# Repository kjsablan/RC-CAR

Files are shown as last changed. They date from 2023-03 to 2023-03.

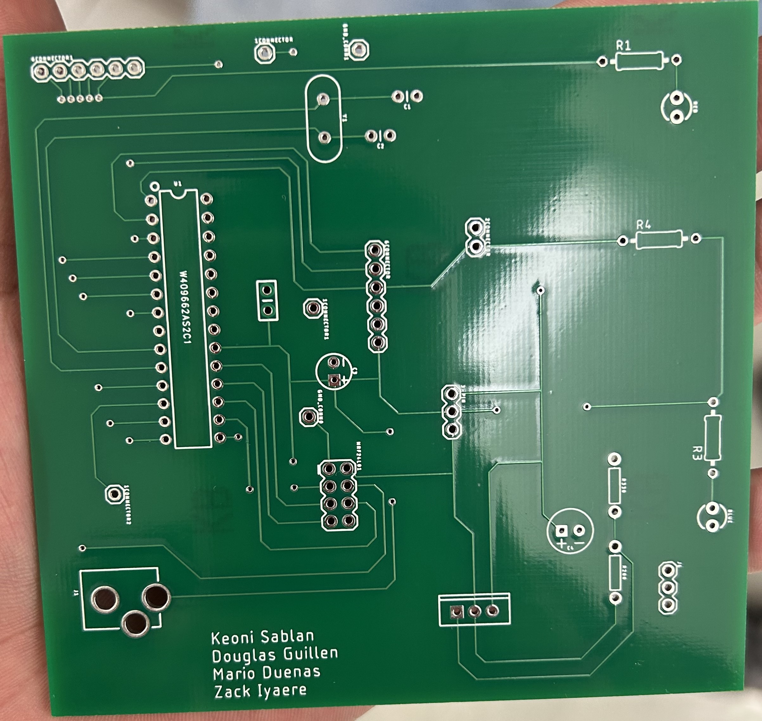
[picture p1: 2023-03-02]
PCB.jpg

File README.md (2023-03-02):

# RC CAR
 PCB Design for an RC CAR (Senior Project)
This is a senior design project this is currently in development and will be complete by May 2023.
The Purpose is to design a Printed Circuit Board using the Eagle software to create a circuit schematic, convert it to a board layout, generate the gerber files, and send the files out to a company to print the board. 
Then Using a microcontroller (ATMega 328P) develop firmware and create a product (RC Car)
My group has completed creating the board and now are building the RC Car.
All files (Project Report/Journal article) are still not completed and will be complete at the end of this semester (May 2023)

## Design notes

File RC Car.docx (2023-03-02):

RC Car

Description:

In this project our group is going to build an RC Car from scratch using a ATmega328P microcontroller and a printed circuit board. The goal of this project is to be able to build a functioning radio controlled operated car using a PCB with minimal parts.

The RC car will be powered by a 9V power supply which will be connected to a L298N H-bridge motor driver, four 3V DC motors, an ATmega 328, and an NRF24L01 radio module. The H-bridge can take a 5V-35V voltage and has an on-board 5V voltage regulator, if the voltage from the power supply is less than 12V then we can use the onboard 5V input as an output to power the ATmega 328 which is what we will be doing. The H-bridge has a voltage drop of .7V at each input (2) for the connection of the motors, taking this into account we will have to supply an additional 1.4V to the H-Bridge to power the DC motors.

The H-Bridge will output 5V to power the ATmega 328, from here the NRF24L01 will be connected to the 3.3V Vout pin of the ATmega 328 to power the device. The NRF24L01 also has an onboard 5V voltage regulator. Our group will also build a remote controller to control the RC car, this will consist of a 7.4V-9V power supply, Arduino Uno/Nano, and a joystick. Firmware will be added onto both and is shown below.

Areas of Responsibility:

Keoni Sablan: RC Car Electrical circuit/components

Douglas Guillen: Remote control electrical circuit/PCB design

Mario Duenas: Firmware/ PCB design

Zack Iyaere: Firmware Remote control

BOM

parts(data sheet) | Cost ($)
PCB | x
ATMega328P Microcontroller (already have): amazon (https://www.amazon.com/Deegoo-ATmega328P-Microcontroller-Board-Arduino/dp/B07R9VWD39?hvadid=459728334703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) data sheet (https://ww1.microchip.com/downloads/en/DeviceDoc/Atmel-7810-Automotive-Microcontrollers-ATmega328P_Datasheet.pdf) | Provided by Lab
L298N H-Bridge: datasheet (https://discord.com/channels/1014667238906789929/1014667239418515519/1019386833265770526) amazon (https://www.amazon.com/Qunqi-Controller-Module-Stepper-Arduino/dp/B014KMHSW6?hvadid=167139094796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) | $6.99
NRF24 radio: amazon (https://www.amazon.com/Wireless-Transceiver-Antenna-Compatible-nRF24L01/dp/B09J2LBZPT?cv_ct_cx=nrf24l01) | $6.89
4 DC geared motors + wheels: amazon (https://www.amazon.com/ApplianPar-Shaft-Gearbox-Plastic-Arduino/dp/B086D5M65M?hvadid=459579282194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) | $9.55
2 Buck converters (up and down converters?) | $9.19
Sliding switches (JS202011CQN) : amazon (https://www.amazon.com/Components-JS202011CQN-Switch-Slide/dp/B00M1S3DOE) datasheet (https://www.ckswitches.com/media/1422/js.pdf) | $1.74
Arduino Nano board Amazon Arduino (https://www.amazon.com/LAFVIN-Board-ATmega328P-Micro-Controller-Arduino/dp/B07G99NNXL) | $24.99
Voltage regulator https://www.digikey.com/en/products/detail/onsemi/LM317MTG/918507 | $0.78

Block Diagram:

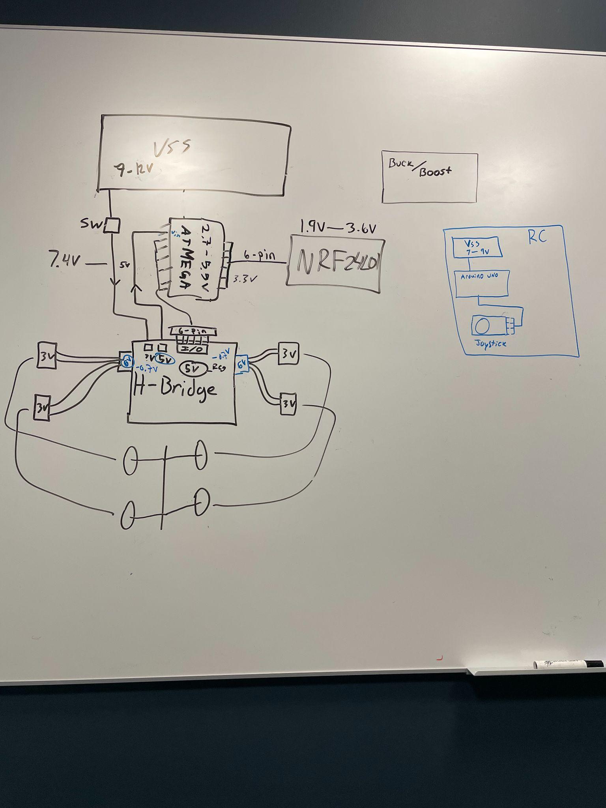
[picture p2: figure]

Sources:

- https://lastminuteengineers.com/nrf24l01-arduino-wireless-communication/
- transmitter-receiver-setup-d73279 (https://create.arduino.cc/projecthub/Arnov_Sharma_makes/arduino-based-nrf24-transmitter-receiver-setup-d73279)
- https://create.arduino.cc/projecthub/Arnov_Sharma_makes/arduino-based-nrf24-t
- https://www.youtube.com/watch?v=Bs0QOjdiyOw
- https://maker.pro/pcb/projects/remote-control-car
- NRF24L01 RF Module Pinout, Arduino Examples, Applications, Features (microcontrollerslab.com) (https://microcontrollerslab.com/nrf24l01-wireless-module-pinout-examples-applications-features/)
- SPI Communication Basics, Working, Types, Applications, Advantages (microcontrollerslab.com) (https://microcontrollerslab.com/introduction-to-spi-communication-protocol/)
- https://www.theengineeringprojects.com/2017/08/introduction-to-atmega328.html
- https://docs.arduino.cc/resources/datasheets/A000066-datasheet.pdf
- https://www.arduino.cc/en/uploads/Main/ArduinoNanoManual23.pdf
- https://create.arduino.cc/projecthub/muhammad-aqib/nrf24l01-interfacing-with-arduino-wireless-communication-0c13d4

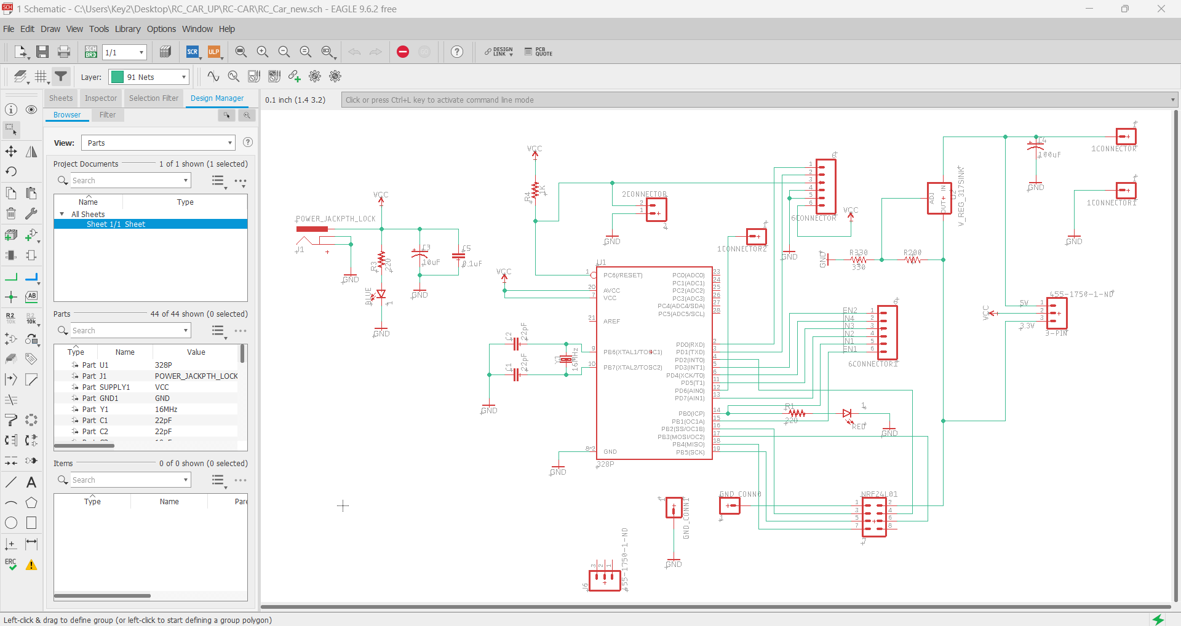
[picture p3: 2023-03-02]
PCB_Schematic.png

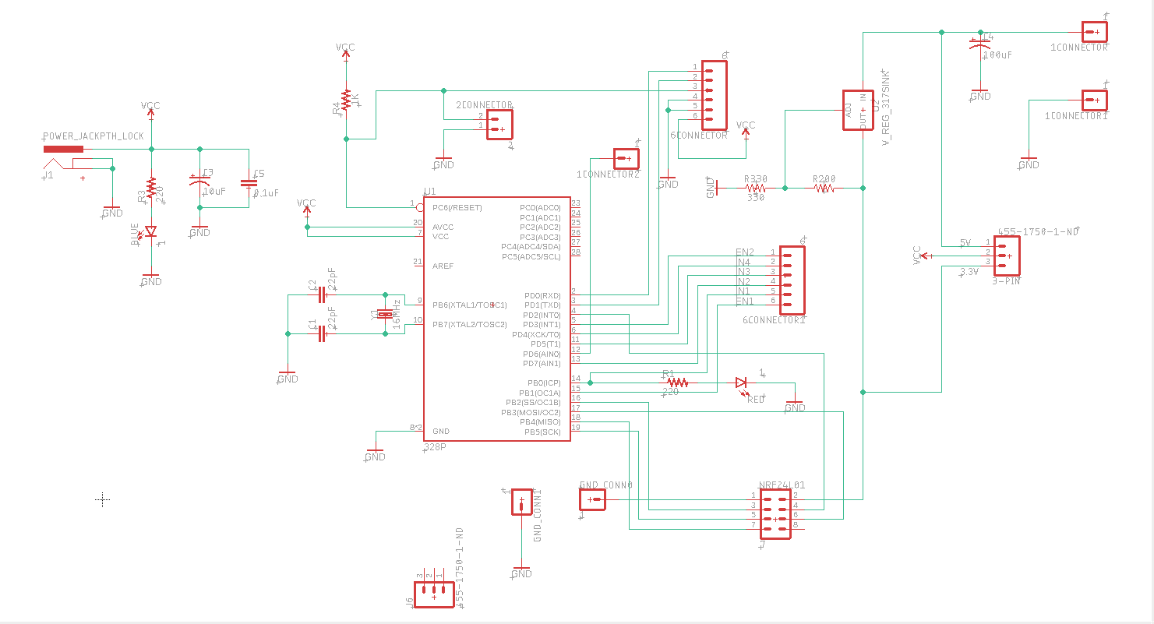
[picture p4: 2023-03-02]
RC_CAR_Schematic.png

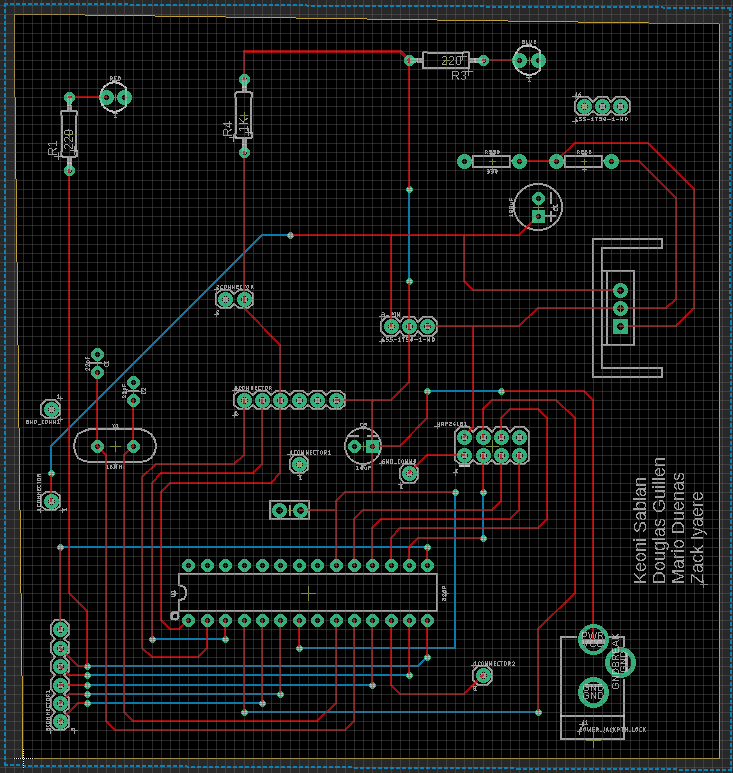
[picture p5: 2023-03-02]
RC_CAR_Board.png

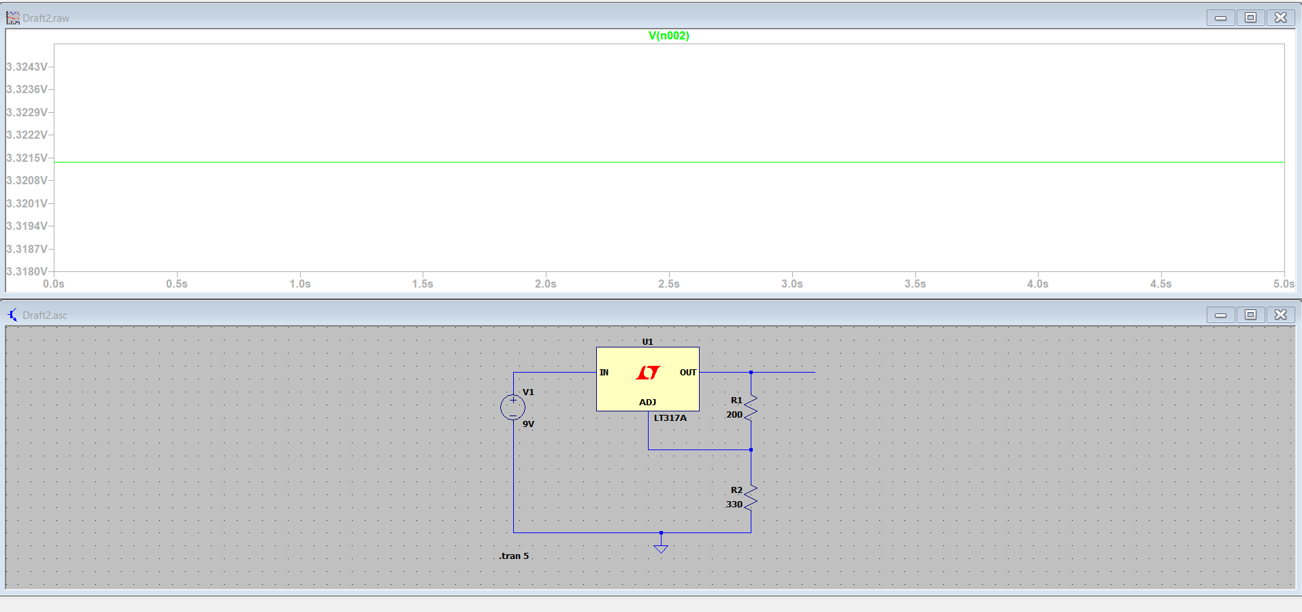
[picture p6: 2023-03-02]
LTpsice_VoltageRegulatorCalc.png

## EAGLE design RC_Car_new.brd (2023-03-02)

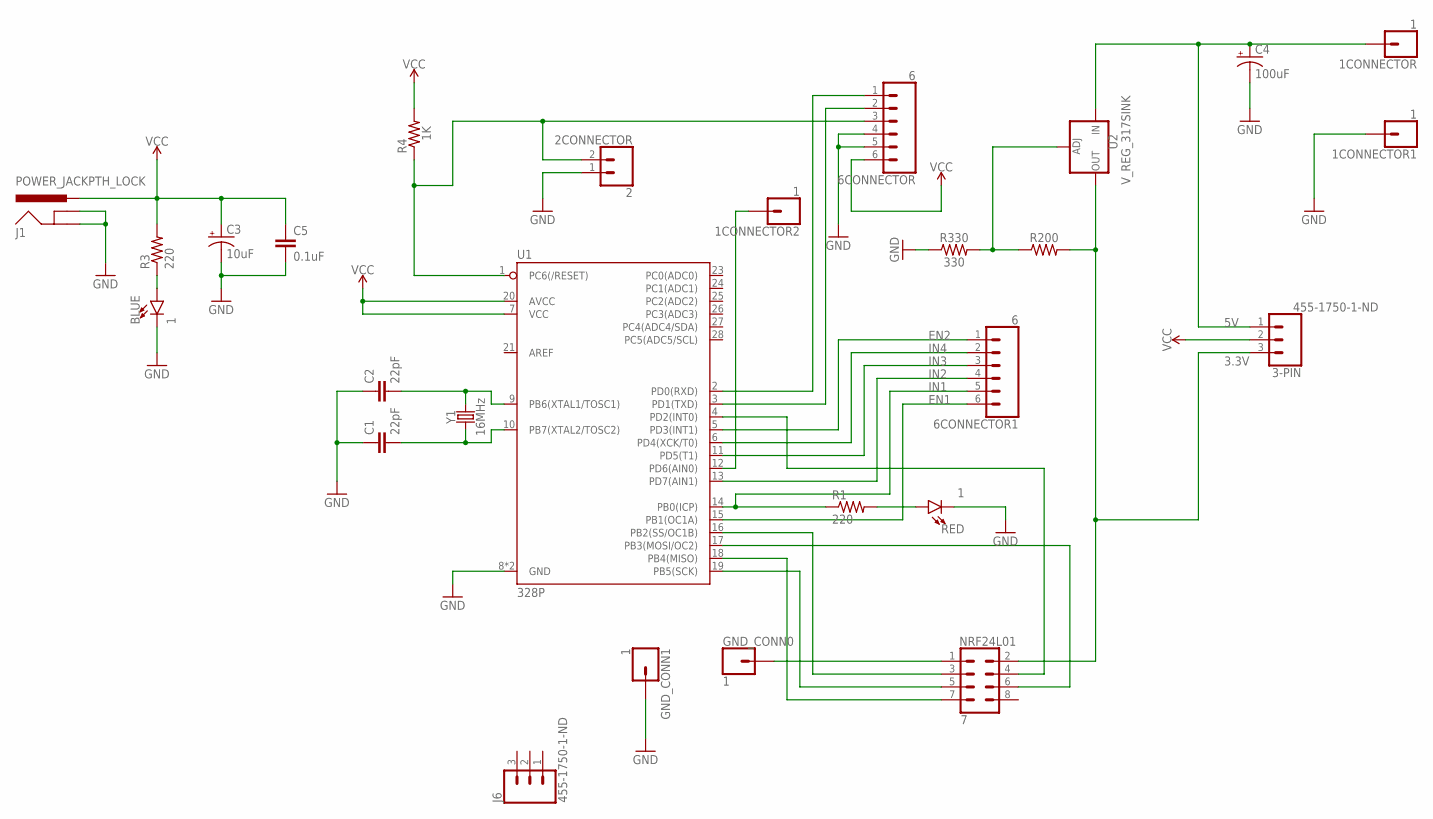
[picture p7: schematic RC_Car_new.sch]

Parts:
1CONNECTOR, 1CONNECTOR1, 1CONNECTOR2: 1; 1X01
2CONNECTOR: 2; 1X02
3-PIN: 455-1750-1-ND; 1X03
6CONNECTOR, 6CONNECTOR1: 6; 1X06
BLUE: 1; LED_3MM
C1, C2: 22pF; CAP-PTH-2.54
C3: 10uF; CPOL-RADIAL-2.5MM-5MM
C4: 100uF; CPOL-RADIAL-2.5MM-6.5MM
C5: 0.1uF; CAP-PTH-SMALL-KIT
GND_CONN0, GND_CONN1: 1; 1X01
J1: POWER_JACKPTH_LOCK; POWER_JACK_PTH_LOCK
J6: 455-1750-1-ND; 1X03
NRF24L01: 7; 2X4
R1, R3: 220; 0207/10
R4: 1K; 0207/10
R200: AXIAL-0.3
R330: 330; AXIAL-0.3
RED: 1; LED_3MM
U1: 328P; DIP28
U2: V_REG_317SINK; TO220-ADJ
Y1: 16MHz; HC49US

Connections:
3.3V: 3-PIN.3, NRF24L01.2, R200.P$2 (2), U2.OUT
5V: 1CONNECTOR.1, 3-PIN.1, C4.1 (+), U2.IN
EN1: 6CONNECTOR1.6, U1.15 (PB1(OC1A))
EN2: 6CONNECTOR1.1, U1.5 (PD3(INT1))
GND: 1CONNECTOR1.1, 2CONNECTOR.1, 6CONNECTOR.4, 6CONNECTOR.5, BLUE.K (C), C1.1, C2.1, C3.2 (-), C4.2 (-), C5.2, GND_CONN1.1, J1.GND, J1.GNDBREAK, R330.P$1 (1), RED.K (C), U1.8 (GND), U1.22 (GND)
IN1: 6CONNECTOR1.5, R1.1, U1.14 (PB0(ICP))
IN2: 6CONNECTOR1.4, U1.13 (PD7(AIN1))
IN3: 6CONNECTOR1.3, U1.11 (PD5(T1))
IN4: 6CONNECTOR1.2, U1.6 (PD4(XCK/T0))
unnamed: 2CONNECTOR.2, 6CONNECTOR.3, R4.1, U1.1 (PC6(/RESET))
unnamed: BLUE.A, R3.1
unnamed: C2.2, U1.9 (PB6(XTAL1/TOSC1)), Y1.2
unnamed: C1.2, U1.10 (PB7(XTAL2/TOSC2)), Y1.1
unnamed: 1CONNECTOR2.1, U1.12 (PD6(AIN0))
unnamed: R1.2, RED.A
unnamed: GND_CONN0.1, NRF24L01.1
unnamed: NRF24L01.3, U1.16 (PB2(SS/OC1B))
unnamed: 6CONNECTOR.1, U1.2 (PD0(RXD))
unnamed: 6CONNECTOR.2, U1.3 (PD1(TXD))
unnamed: R200.P$1 (1), R330.P$2 (2), U2.ADJ
unnamed: NRF24L01.4, U1.4 (PD2(INT0))
unnamed: NRF24L01.6, U1.17 (PB3(MOSI/OC2))
unnamed: NRF24L01.5, U1.19 (PB5(SCK))
unnamed: NRF24L01.7, U1.18 (PB4(MISO))
VCC: 3-PIN.2, 6CONNECTOR.6, C3.1 (+), C5.1, J1.PWR, R3.2, R4.2, U1.7 (VCC), U1.20 (AVCC)

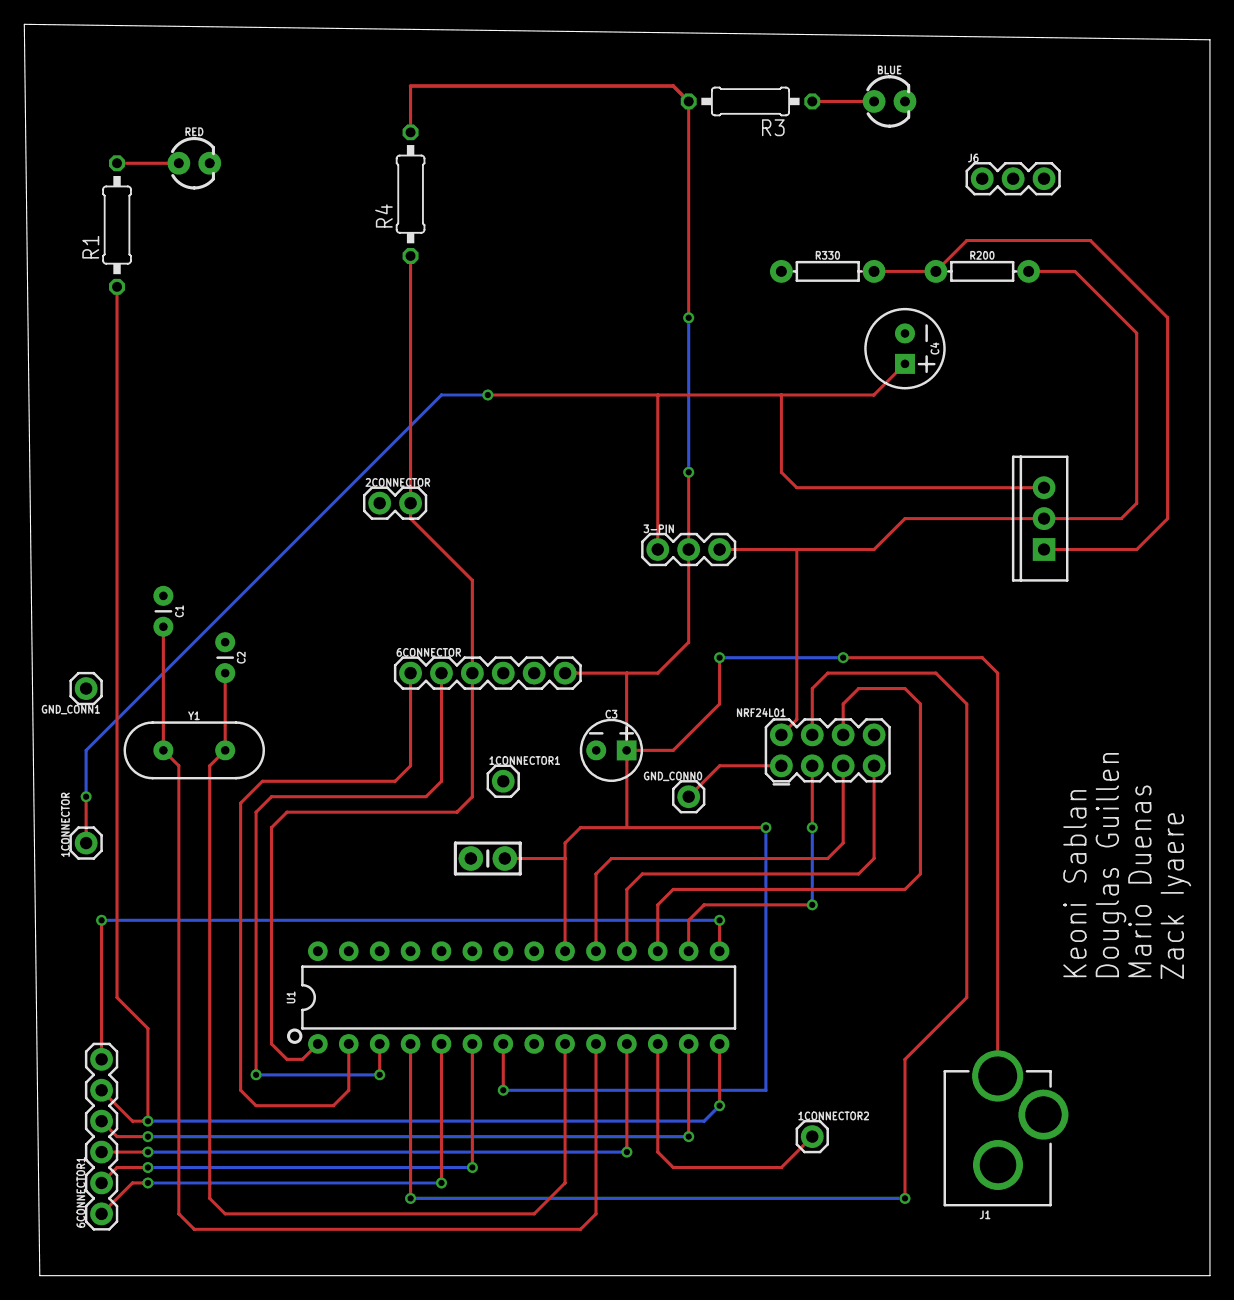
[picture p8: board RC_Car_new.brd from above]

Board: 2 copper layers, 97.5 x 102.9 mm, 27 parts (0 on the bottom side), 25 nets.

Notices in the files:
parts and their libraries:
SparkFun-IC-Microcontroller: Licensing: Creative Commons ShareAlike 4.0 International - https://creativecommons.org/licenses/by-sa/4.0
